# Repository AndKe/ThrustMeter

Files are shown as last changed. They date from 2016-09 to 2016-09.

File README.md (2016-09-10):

# ThrustMeter
An thrustmeter for measuring thrust, power, efficiency of RC motors, propellers, ESC's.

Grams per watt (g/W) is calculated based on voltage and current, and a precise thrust measurement.
Serial data is output for collection/plotting by DataExplorer http://www.nongnu.org/dataexplorer/  - the xml is included in "dataexplorer" directory.

To be compiled in Arduino, usually for "Leonardo" board.
Looks like: https://www.youtube.com/watch?v=S2vaC5SftQc

The weight-cell is vertically mounted thru the center hole of the sled:
https://github.com/AndKe/ThrustMeter/blob/master/mount/Thrustmeter-assembled%20view.png
This design allow plenty of vibration dampening material(s) between sled and weight cell, giving much better thrust data.

# Extras:
The folder "mount" contains OpenSCAD files for 3D printed testbench.
There will be a description of the hardware and connections (which is now kind of self-explained in source ?)

# License  GNU GPL
I'll gladly accept pull requests with improvenets.

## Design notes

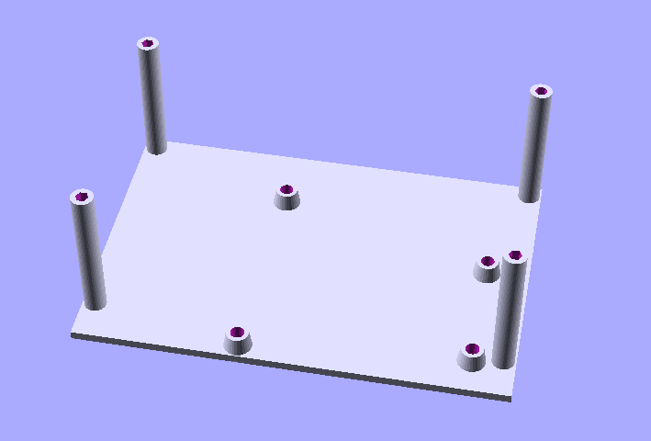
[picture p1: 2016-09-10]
mount/Leonardo+4x20LCD-holder-view.png

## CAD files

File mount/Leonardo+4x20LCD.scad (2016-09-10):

//-----------------------------------------------------------
//--------------------BOTTOM----------------------------
//-----------------------------------------------------------


include <arduino.scad>
unoDimensions = boardDimensions( UNO );


module bottom() {
	
	difference () { 

		union(){
	    cube ([100,68,2], center=true);  //bottom
        	translate ([-47,-24,0])  //lower left display holder
            screwhole(34);
           	translate ([47,-24,0])   //lower right display holder
            screwhole(34);

            translate ([-47,31,0])  //upper left display holder
            screwhole(34);
           	translate ([47,31,0])   //upper right display holder
            screwhole(34);

        	rotate (270,[0,0,1])
            translate( [-(unoDimensions[0] - 33), -26, -1] ) union() {
            standoffs(LEONARDO, mountType=TAPHOLE, height=6);
            //boardShape(LEONARDO, offset = 3);
        }

		}
	
		}

    }





module screwhole(height) {
    	difference () { 
    	    
          cylinder (h=height, r=2.6,center=false,$fn=50); // 1.6=tight 3mm screw hole
          cylinder (h=(height+1), r=1.5,center=false,$fn=6); // 1.6=tight 3mm screw hole
	    }

    }
//-----------------------------------------------------------
//---------------------S100 Holder----------------------------
//-----------------------------------------------------------
module S100HOLDER() { 

$pt=3.2; //(plate thickness)
$bp=3.2; //bottom plate thickness
$hp=3; //holder plate thickness
$w = 107;  //camera width
$h1= 68.5; // height on bearing side
$h2= 68.5; // height on servo side


	translate ([0,0,-32])
	cube ([$w,20,$bp], center=true); //bottom plate

			
	translate ([$w/2-$pt*2.5+2,0,$h2/2+2])
	cube ([15,20,$hp], center=true); //servo side top camera-holder

	translate ([-$w/2+$pt*2.5-2,0,$h1/2+2.4])
	cube ([15,20,$hp], center=true); //bearing side top  camera-holder



	difference() {
		translate ([-$w/2,0,1])
		cube ([$pt,20,$h1], center=true); //right side (ball bearing)

		
		translate ([0.4-$w/2,0,3])
		rotate (90,[0,1,0])
		#F683zz(10);

	 }

	difference() {
		union() {
			translate ([$w/2,0,1])
			cube ([$pt,20,$h2], center=true); //left side, (servo)
	        }

		translate ([$w/2,0,3])
		rotate (270,[0,1,0])
	   	#cylinder (h=14, r=1.5,center=true,$fn=6); // 1.6=tight 3mm screw hole

	}




}

//-----------------------------------------------------------
//---------------------S100----------------------------
//-----------------------------------------------------------
// ring on lens increased in length.
module S100() {

	
		color ([ 0.1,0.1,0.1,0.8])
		translate ([0,0,0])
		cube ([100,20,61], center=true); 
		
		translate ([-56,-5,14.5])
		color ([ 0.2,0.2,0.2,0.8])
		cube ([18,7,10], center=true); //USB plug
	
		rotate (90,[1,0,0])
		translate ([13,0,14,])
		color ([ 0.2,0.2,0.2,0.8])
		cylinder (r=25, h=8, center=true, $fn=40); //Lens
		
		rotate (90,[0,0,1])
		translate ([0,-11.5,-35,])
		color ([ 0.6,0.6,0.6,0.8])
		cylinder (r=3.8, h=10, center=true, $fn=10); //bottom screw


}




//-----------------------------------------------------------
//---------------------HS65----------------------------
//-----------------------------------------------------------

module HS65(bolts) {
	if (bolts > 0)  {  
		color ([ 0,0,0,0.8]) {
				cube ([12,32.5,2], center=true);   //plate with holes
		
				translate ([0,-14.3,0])
				cylinder (r=0.8, h=15, center=true, $fn=6); //left side center hole
				
				translate ([0,14.3,0])
				cylinder (r=0.8, h=15, center=true, $fn=6); //right side center hole

	if (bolts == 2)  {  

			translate ([0,6,13])
			rotate (180,[0,0,0])
			MXLPulley();
			}
		}
	}
else
	{
		color ([ 0,0,0,0.8]) {
			difference() {
				cube ([12,32.5,2], center=true);   //plate with holes
		
				translate ([0,-14.3,0])
				cylinder (r=1.2, h=10, center=true, $fn=6); //left side center hole
				
				translate ([0,14.3,0])
				cylinder (r=1.2, h=10, center=true, $fn=6); //right side center hole
		
			}
		}

	}

	translate ([0,0,-8.15])
			cube ([12,24,20.4], center=true);   //main body (real y=24.5)
		
			translate ([0,4.2,5.3])
			cube ([12,15.2,6.5], center=true);  //gearbox
	
			translate ([0,13,-14])
			cube ([7,3,5], center=true);  //cable output
	
	
	translate ([0,6,10])
			color ([ 1,1,1,0.7]) 
		 	cylinder (r=2.25, h=5, center=true, $fn=6); // drive shaft

}


//-----------------------------------------------------------
//---------------------F683zz----------------------------
//-----------------------------------------------------------
//3x7x3mm Shielded Bearing Sizes
//xtend variable prolongs the shaft
module F683zz($xtend) {    

$bore = 3; //Bore
$outer_d = 7.2; //Outer Diameter
$flange_o = 8.3;  //Flange Outer Diameter
$flange_w = 0.8; //Flange Width (part of the bearing width)
$width = 3;  //Bearing width


	color ([ 0.5,0.6,0.2,0.8])	{	
		cylinder (r=($outer_d/2), h=$width, center=true, $fn=24); // main body
		translate ([0,0,($width/2-$flange_w/2)])
   		cylinder (r=($flange_o/2), h=$flange_w, center=true, $fn=24); //Flange 
		cylinder (r=$bore/2, h=$width+$xtend, center=true, $fn=24); // intended ring
	}
}


//-----------------------------------------------------------
//---------------------MXLPulley----------------------------
//-----------------------------------------------------------

module MXLPulley() {   		
$bore = 3; //Bore
$outer_d = 20; //Outer Diameter
$flange_o = 25;  //Flange Outer Diameter
$flange_w = 1; //Flange Width (part of the bearing width)
$width = 8.8;  //Bearing width

difference() {
		union() {
				color ([ 0.5,0.6,0.2,0.8])	{	
				cylinder (r=($outer_d/2), h=$width, center=true, $fn=24); // main body
				translate ([0,0,($width/2-$flange_w/2)])
		   		cylinder (r=($flange_o/2), h=$flange_w, center=true, $fn=24); //Flange 
					}
	cylinder (r=$bore/2, h=$width+2, center=true, $fn=6); // intended ring

		}
	}
}
//-----------------------------------------------------------
//---------------------MXLRing----------------------------
//-----------------------------------------------------------

module MXLRing() {   		
$bore = 3; //Bore
$outer_d = 28; //Outer Diameter
$flange_o = 30;  //Flange Outer Diameter
$flange_w = 1; //Flange Width (part of the bearing width)
$width = 6;  //Belt area width

difference() {
		union() {
   	color ([ 0.5,0.6,0.2,0.8])	{	
		cylinder (r=($outer_d/2), h=$width, center=true, $fn=50); // main body
		translate ([0,0,($width/2-$flange_w/2)])
   		cylinder (r=($flange_o/2), h=$flange_w, center=true, $fn=50); //Flange 
		}
		}

		cylinder (r=$bore/2, h=$width+2, center=true, $fn=7); // hole
	 	translate ([0,0,-2])  
		cylinder (r=($outer_d/2-1.5), h=$width-3, center=true, $fn=50); // main body reduction
}
	}


//-----------------------------------------------------------
//---------------------Mounts----------------------------
//-----------------------------------------------------------
module MOUNTV3M() {    

	difference () {
		cube ([6,6,18], center=true); //
	 	translate ([0,0,7])  
	    cylinder (r=1.6, h=16, center=true, $fn=6); 
	
		translate ([5,0,-5])		
		rotate (40,[0,1,0])
		cube ([12,6.1,18], center=true); //

	}
}

//-----------------------------------------------------------
module MOUNT3M() {    

	difference()  {
			cube ([6,6,6], center=true);  //add lower mount
			cylinder (h=14, r=1.7,center=true,$fn=6); //3mm screw hole is 1.7
		}

}

//-----------------------------------------------------------
//---------------------BODY----------------------------
//-----------------------------------------------------------
module BODY(option) {


	if (option==1)  {  


		difference (){
			S100HOLDER(); 
		
			translate ([0,0,0.5])
			#S100();  //
			}		
				translate ([5,1,63])
				rotate (90,[1,0,0])
				topbar();  

	translate ([58.5,0,3.1])
	rotate (90,[0,1,0])
	MXLRing();

	translate ([5,-0.5,70])
	rotate (180,[0,1,0])
	Hanger();

	}

if (option==2)  {     //with topbar - printable

		difference (){
			S100HOLDER(); 
		
			translate ([0,0,0.5])
			#S100();  //

		}
				translate ([0,7,56])
				rotate (90,[1,0,0])
				topbar();  
	
	translate ([0,7,25])
	rotate (270,[1,0,0])
	MXLRing();

	rotate (90,[1,0,0])
	translate ([35,70,2.5])
	Hanger();

}
		

if (option==0)  {    //no topbar, printable

		difference (){
			S100HOLDER(); 
		
			translate ([0,0,0.5])
			#S100();  //
//				translate ([4.5,1,51])
//				rotate (90,[1,0,0])
//				topbar();  
	
 }
	rotate (90,[1,0,0])
	translate ([0,50,2.5])
	Hanger();

}
}

bottom();

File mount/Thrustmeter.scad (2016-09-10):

//-----------------------------------------------------------
//--------------------BOTTOM----------------------------
//-----------------------------------------------------------



module LOADCELLHOLDER() {
	
	difference () { 

		   cube ([55,12.5,25.4], center=true);  //bottom
        	translate ([0,0,27.5])  //lower left display holder
            
         #LOADCELL();

        translate ([24,0,-1])   //left
        rotate (90,[1,0,0])
        #cylinder (50, r=1.7,center=true,$fn=50); // 1.6=tight 3mm screw hole

        translate ([10,0,3])   //2
        rotate (90,[1,0,0])
        #cylinder (50, r=1.7,center=true,$fn=50); // 1.6=tight 3mm screw hole
     
     
        translate ([-24,0,-1])   //right
        rotate (90,[1,0,0])
        #cylinder (50, r=1.7,center=true,$fn=50); // 1.6=tight 3mm screw hole

        translate ([-10,0,3])   //2
        rotate (90,[1,0,0])
        #cylinder (50, r=1.7,center=true,$fn=50); // 1.6=tight 3mm screw hole
        
        
    }
    
    


    }





module screwhole(height) {
    	difference () { 
    	    
          cylinder (h=height, r=2.6,center=false,$fn=50); // 1.6=tight 3mm screw hole
          cylinder (h=(height+1), r=1.5,center=false,$fn=6); // 1.6=tight 3mm screw hole
	    }

    }

//-----------------------------------------------------------
//---------------------LOADCELL---------------------------
//-----------------------------------------------------------

module LOADCELL() {

	
		color ([ 0.1,0.1,0.1,0.8])
		cube ([12.9,12.9,80.5], center=true); 
		
        translate ([0,0,35])   //top
        rotate (270,[0,1,0])
	    color ([ 0.2,0.2,0.2,0.8])
		cylinder (r=2.1, h=70, center=true, $fn=40); //bolt

        
        translate ([0,0,20])   //below top
        rotate (270,[0,1,0])
	    color ([ 0.2,0.2,0.2,0.8])
		cylinder (r=2.1, h=70, center=true, $fn=40); //bolt

        translate ([0,0,-20])   //above bottom
        rotate (270,[0,1,0])
	    color ([ 0.2,0.2,0.2,0.8])
		cylinder (r=2.5, h=70, center=true, $fn=40); //bolt
    
        translate ([0,0,-35])   //bottom
        rotate (270,[0,1,0])
	    color ([ 0.2,0.2,0.2,0.8])
		cylinder (r=2.5, h=70, center=true, $fn=40); //bolt

/*forsenkning
        
        translate ([0,0,-20])   //above bottom left
        rotate (270,[0,1,0])
        translate ([0,0,-25.3])   
	    color ([ 0.2,0.2,0.2,0.8])
		cylinder (r=4, h=4.5, center=true, $fn=40); //bolt
    
        translate ([0,0,-35])   //bottom
        rotate (270,[0,1,0])
        translate ([0,0,-25.3])   
	    color ([ 0.2,0.2,0.2,0.8])
		cylinder (r=4, h=4.5, center=true, $fn=40); //bolt

        translate ([0,0,-20])   //above bottom right
        rotate (270,[0,1,0])
        translate ([0,0,25.3])   
	    color ([ 0.2,0.2,0.2,0.8])
		cylinder (r=4, h=4.5, center=true, $fn=40); //bolt
    
        translate ([0,0,-35])   //bottom
        rotate (270,[0,1,0])
        translate ([0,0,25.3])   
	    color ([ 0.2,0.2,0.2,0.8])
		cylinder (r=4, h=4.5, center=true, $fn=40); //bolt
*/
}

module SLEDHOLDER() {

		difference () { 

    union() {
		   translate ([0,6,0])      
           cube ([20,63,12.5], center=true);  //pylon
           translate ([0,-30,0])   
           cube ([20,14,40], center=true);  //top part
  
           
        }
                

        translate ([6,34,0])   //lower screw hole
        #cylinder (50, r=1.7,center=true,$fn=50); // 1.6=tight 3mm screw hole

        translate ([-6,26,0])   //upper screw hole
        #cylinder (50, r=1.7,center=true,$fn=50); // 1.6=tight 3mm screw hole
        
        translate ([0,-30,0])   
        cube ([24,7,32], center=true);  //sled model

        translate ([0,-35,0])   
        cube ([24,7,23], center=true);  //sled grip top hole 

        translate ([7,-35,0])   
        #cube ([6,4,45], center=true);  //sled grip width reduction

        translate ([-7,-35,0])   
        #cube ([6,4,45], center=true);  //sled grip width reduction
    }
    
        
    }
        

module MOTORMOUNT() {

difference () {
	union () { 
        
		color ([ 0.1,0.1,0.1,0.8])
		cylinder (r=20, h=2.5, center=true, $fn=200); //bolt
		
        //rotate (45,[0,0,45])    
        translate ([0,0,9])   //mount box
        cube ([14,30,18], center=true); 
          
        
    }
    
    
        translate ([0,0,10.3])   //mount box (horizontal slot)
        #cube ([6.5,30,18], center=true); 
	
        translate ([0,0,10.3])   //mount box (vertictal slot)
        cube ([30,20,18], center=true); 
	
    
        rotate (45,[0,0,45])    
        translate ([0,10,0])   //mount slot
        cube ([3,12,8], center=true); 
    
        rotate (45,[0,0,45])    
        translate ([0,-10,0])   //mount slot
        cube ([3,12,8], center=true); 
    
        rotate (135,[0,0,1])    
        translate ([0,10,0])   //mount slot
        cube ([3,12,8], center=true); 
    
        rotate (135,[0,0,1])    
        translate ([0,-10,0])   //mount slot
        cube ([3,12,8], center=true); 
    
    
        translate ([0,12.5,15])   //left locking pin
        rotate (90,[0,1,0])    
        #cylinder (r=1, h=50, center=true, $fn=40); 

        translate ([0,-12.5,15])   //rear locking pin
        rotate (90,[0,1,0])        
        #cylinder (r=1, h=50, center=true, $fn=40); 

        translate ([0,0,0])   //left locking pin
        #cylinder (r=4.5, h=10, center=true, $fn=40); 
    
}
}


module SLED() {

        
				
      difference() {
       
        translate ([0,0,93])   //main sled plate
        cube ([6,30,145], center=true); 
        
        translate ([0,12.5,33])   //front locking pin
        rotate (90,[0,1,0])    
        #cylinder (r=1, h=50, center=true, $fn=40); 

        translate ([0,-12.5,33])   //rear locking pin
        rotate (90,[0,1,0])    
        #cylinder (r=1, h=50, center=true, $fn=40); 
          
        translate ([0,0,27])   //motor-axle-slot
        #cube ([9.5,9.5,15], center=true); 
 
        translate ([0,0,108])   //loadcell-slot
        #cube ([14,14,30], center=true); 
 
        translate ([0,12.5,60])   //front locking slot 1
        #cube ([10,5,10], center=true); 
        translate ([0,-12.5,60])   //front locking slot 2
        #cube ([10,5,10], center=true); 

        translate ([0,12.5,145])   //rear locking slot 1
        #cube ([10,5,10], center=true); 
        translate ([0,-12.5,145])   //rear locking slot 2
        #cube ([10,5,10], center=true); 

     //   translate ([0,0,18]) 
  //     #MOTORMOUNT();

    }
        
        
		
}


////  UNCOMMENT INDIVIDUAL PARTS TO PRINT


module BODY(option) {

if (option==0)  {
rotate (90,[1,0,0])
LOADCELLHOLDER();
}

if (option==1)  {  
translate ([60,0,0])   
MOTORMOUNT();
}

if (option==2)  {
translate ([-60,0,0])
rotate (90,[0,1,0])
SLED();
}
		

if (option==3)  {
rotate (90,[0,1,0])
translate ([-120,0,0])
SLEDHOLDER();
}

if (option==4)  {

rotate (-90,[1,0,0])
translate ([-90,0,0])
SLEDHOLDER();

rotate (-90,[1,0,0])
translate ([-4,0,0])
SLEDHOLDER();

rotate (270,[0,1,0])
translate ([30,0,-56])
SLED();

rotate (-90,[0,1,0])
translate ([30,0,-38])   
MOTORMOUNT();
    
}
}







//number defines printable parts, or display
BODY(4); //0=LOADCELLHOLDER, 1=MOTORMOUNT, 2=SLED ,3=SLEDHOLDER, 4=assembled view

////

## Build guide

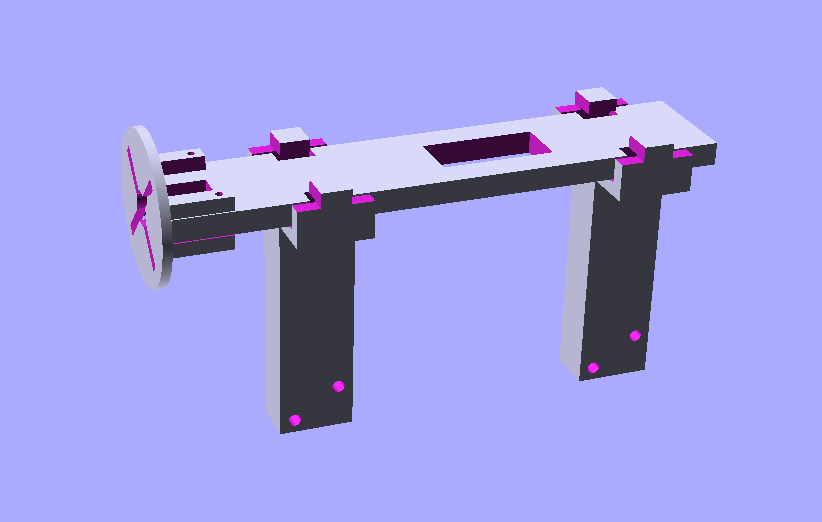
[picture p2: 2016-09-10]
mount/Thrustmeter-assembled view.png

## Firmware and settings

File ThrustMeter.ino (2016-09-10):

/*

todo:
-efficiency mode: for xx throttle for xx seconds.  - measure power consumed. (measure mAh, Wh consumed)
-add a "playback" mode for throttle with repeatable varaition within a given range, for xx seconds. (measure mAh, Wh consumed.)
-add a sync-test mode, run 5-20, 5-50 jump routine. 

1.0  Initial version.


Leonardo
USB == Serial
RX/TX == Serial1

----------------------------------------------
0tx
1rx
2 LCD
3-BTN_Run
4 LCD
5-LCD
6-LCD
7 LCD
8 LCD
9-LCD
10-PWM Out (ESC)  //Counter1 capable PWM output(PB6) , default 490hz PWM
11-
12
13-

A0 analog I in
A1 analog V in
A2 PowerLED
A3
A4
A5
------------------------------------------------
HD44780 pinout *=needed
1 GND
2 +5V
3 Contrast adj.
4 RS*
5 RW*
6 EN*
7 DB0
8 f
9 DB2
10DB3
11DB4*
12DB5*
13DB6*
14DB7*
15 backlit +
16 Baklit GND
*/

#include <Servo.h>

Servo ESC;

//#define DEBUG
//#define DEBUG_g
//#define DEBUG_V
//#define DEBUG_I
//#define DEBUG_Imul

#ifndef cbi
#define cbi(sfr, bit) (_SFR_BYTE(sfr) &= ~_BV(bit))
#endif
#ifndef sbi
#define sbi(sfr, bit) (_SFR_BYTE(sfr) |= _BV(bit))
#endif


#include <LiquidCrystal.h>
#define LCD_RS 2
#define LCD_RW 4
#define LCD_EN 5
#define LCD_D4 6
#define LCD_D5 7
#define LCD_D6 8
#define LCD_D7 9
#define LCD_CHARS 20
#define LCD_LINES 4
LiquidCrystal lcd(LCD_RS, LCD_RW, LCD_EN, LCD_D4, LCD_D5, LCD_D6, LCD_D7);
#define Ipin  A0  //reads 0-1024 (
#define Vpin  A1
#define Gpin  A2
#define ESCpin 10

#define b_run 3

//#define mVA 0.02 //ACS758 100A returns 20mV/Amp.
//#define mVA 0.04 //ACS758 50A returns 40mV/Amp.

#define Vmul 0.0247723705 //Voltage per AD step, 28v/1024 steps.
#define Imul 0.039
//2.54v/1024= 0,002392578 v/step.   100A sensor = 40mV/Step.  ca 16,7 steps per A. teoretisk 1A  = AD d16  ,= multiplier:  0,05981445    Hvis AD er 256 = , betyr det ca 15.329A
#define ADiOffset 0  // AD offset,  (measured when No current)
#define gmul 5.7452488  // Thrust multiplicator
#define ADgOffset 27  // Thrust Offset


float V = 0;  //sensed voltage
float I = 0;  //sensed current
float gw = 0;  //gram/watt
float maxgw = 0;  //gram/watt
float W = 0; //calculated power
float maxW = 0;
bool active = false;
bool newdata = false;
unsigned long millisLCD = 0;
unsigned long millisBTN = 0;
unsigned long millisNOBTN = 0;
unsigned long millisSEC = millis();
unsigned long millisAD = 0; //last AD average
int BTNseq = 0; //how many passes did we had w/o buton press.
uint16_t Ia ;//Analog read I
uint16_t Va ;//Analog read V
float g = 0 ;//Analog read thrust (gram)
float maxg = 0;//Analog read thrust (gram)



uint16_t ADi = 0; //AD raw data
uint32_t ADDi = 0;      // the readings from the analog input
uint16_t ADDicount = 0;
uint16_t ADv = 0;
uint32_t ADDv = 0;
uint16_t ADDvcount = 0;
uint16_t ADg = 0;
uint32_t ADDg = 0;
uint16_t ADDgcount = 0;
uint8_t  throttle = 0;
uint8_t  maxgthrottle = 0;
uint8_t  maxgwthrottle = 0;
void setup() {

  pinMode(b_run, INPUT_PULLUP);
  pinMode(Gpin, INPUT);
  pinMode(Ipin, INPUT);
  pinMode(Vpin, INPUT);
  pinMode(ESCpin, OUTPUT);

  lcd.begin(LCD_CHARS, LCD_LINES);
  lcd.clear();

  ESC.attach(ESCpin);


#ifdef DEBUG
  delay(2000);
  Serial.begin(115200);
  //while (!Serial) ;// wait for serial port to connect. Needed for Leonardo only
#endif
  CalibrateESC();

}


void loop() {

  //*********** UPDATE LCD
  if (millis() - millisLCD > 150)  {
    UpdateLCD();
  }

  if (millis() - millisSEC >= 300 && !digitalRead(b_run))  {  //if more than half a sec since last throttle change, calculate

    if (g > maxg) {
      maxg = g;   //new highest thrust
      maxgthrottle = throttle;
    }
    if (g / W > maxgw && W!=0 && g!=0) {maxgw = g / W;  maxgwthrottle = throttle;} //max grams
  }


  //*********** Process standard AD inputs
  ADi = ReadADC(0);  //I = A0
  //if (ADi >=ADiOffset) ADi = ADi - ADiOffset; else ADi=0 ;//   suitable for 100A sensor
  ADDi = ADDi + ADi;
  ADDicount ++;

  ADv = ReadADC(1);  //V = A1
  ADDv = ADDv + ADv;
  ADDvcount ++;

  ADg  = ReadADC(2);  //thrust = A2
  if (ADg >= ADgOffset)   ADDg = ADDg + (ADg - ADgOffset) ;
  ADDgcount ++;


  if (millis() - millisAD > 100)  {    //sample AD continously and read out after xx ms.
    millisAD = millis();
    I = (ADDi / ADDicount) * Imul;
    //Serial.println(ADDicount);
    ADDicount = 0;
    ADDi = 0;
    // PWMout();

    V = (ADDv / ADDvcount) * Vmul;
    ADDvcount = 0;
    ADDv = 0;

    W = I * V;
    if (W > maxW) maxW=W;
    if (W > 0) gw = g / W; else gw = 0;

    g = (ADDg / ADDgcount) * gmul;
    newdata=true;
//Serial.println(ADDgcount);  //4 is max
    ADDgcount = 0;
    ADDg = 0;


  }



    
  if (!digitalRead(b_run))  {  //button pressed
  
  if (newdata) { Writelog(); newdata=false;}
    //buttom pressed, START procedure
    if (!active) { //We have just started, clear old stats
      maxg = 0;  //max grams
      maxgw = 0; //max grams/W
      maxW=0;
      maxgthrottle = 0;//throttle @ max grams
      maxgwthrottle = 0; //throttle @ max efficiency
      millisSEC = millis();  //start counter
      active = true;
    }

    //are we in soft-start range ?
    if (throttle <  15 && (millis() - millisSEC) > 300)    {
      throttle += 1;  // do slow start with 1% each 300ms
      ESC.write((throttle + 40)); //  0...180 are valid position
      millisSEC = millis();  //count time since last increase
    } else {     //now normal throttle increase
      if (throttle <  100 && throttle >= 15 && (millis() - millisSEC) > 980) {
        throttle += 5;
        ESC.write((throttle + 40)); //  0...180 are valid position
        millisSEC = millis();  //count time since last increase
      }
    }
    while (throttle == 100 && (millis() - millisSEC) > 980 && !digitalRead(b_run)) {
          ESC.write((0 + 40)); //  0...180 are valid position
          delay(300);
      }
    
  } else {     //button not pressed
    if (active) {
    throttle = 0;
    ESC.write(40);   //  0...180 are valid position
    active=false;
    }
       if ((millis() - millisSEC) > 1980) {
        Writelog();  //if idle, log every 2 sec
        millisSEC = millis();  //start counter  
    }

  }


} //end loop

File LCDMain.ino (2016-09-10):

void UpdateLCD() {
  lcd.noCursor();
  lcd.setCursor(0, 0);
  lcd.print(V,2);
  lcd.print("V");
  if (V < 10)  lcd.print(" ");
  lcd.setCursor(7, 0);
  if (I < 10)  lcd.print(" ");
  lcd.print(I,2);
  lcd.print("A");

  lcd.setCursor(14 ,0);
  lcd.print(W,0);
  lcd.print("W");
  if (W < 1000) lcd.print(" ");
  if (W < 100) lcd.print(" ");
  if (W < 10)  lcd.print(" ");   


  lcd.setCursor(0, 1);
  lcd.print(g,0);
  lcd.print("g");
  if (g < 1000) lcd.print(" ");
  if (g < 100) lcd.print(" ");
  if (g < 10)  lcd.print(" ");


  lcd.setCursor(6, 1);
  lcd.print(gw,1);
  lcd.print("g/W");
  if (gw < 100) lcd.print(" ");
  if (gw < 10)  lcd.print(" ");


  lcd.setCursor(14, 1);
  lcd.print("@ ");
  lcd.print(throttle);
  lcd.print("%");
  if (throttle < 100) lcd.print(" ");
  if (throttle < 10)  lcd.print(" ");

  lcd.setCursor(0, 2);
  lcd.print("M.eff ");
  lcd.print(maxgw,1);
  lcd.print("g/W");
  if (maxgw < 10)  lcd.print(" ");
  
  lcd.setCursor(14, 2);
  lcd.print("@ ");
  lcd.print(maxgwthrottle);
  lcd.print("%");
  if (maxgwthrottle < 100) lcd.print(" ");
  if (maxgwthrottle < 10)  lcd.print(" ");
  

  lcd.setCursor(0, 3);
  lcd.print("Max ");
  lcd.print(maxg,0);
  lcd.print("g ");
  lcd.print(maxgthrottle);
  lcd.print("% ");
  lcd.print(maxW,0);
  lcd.print("W");
  if (maxW < 100) lcd.print(" ");
  if (maxW < 10)  lcd.print(" ");
  lcd.print("   ");

#ifdef DEBUG_V  
  lcd.print("raw");
  lcd.print(ADv);
  if (ADv < 1000) lcd.print(" ");
  if (ADv < 100) lcd.print(" ");
  if (ADv < 10)  lcd.print(" ");
#endif
#ifdef DEBUG_I  
  lcd.print("raw");
  lcd.print(ADi);
  if (ADi < 1000) lcd.print(" ");
  if (ADi < 100) lcd.print(" ");
  if (ADi < 10)  lcd.print(" ");
#endif
#ifdef DEBUG_g  
  lcd.setCursor(13, 3);
  lcd.print("raw");
  lcd.print(ADg);
  if (ADg < 1000) lcd.print(" ");
  if (ADg < 100) lcd.print(" ");
  if (ADg < 10)  lcd.print(" ");
#endif

}

/*
Display 4x20
01234567890123456789
--------------------
14.72V 30.20A 501W
1032g 16.2g/W @ 100%
M.eff 20.1g/W @ 22%
Max 1200g 100% 123W
*/
